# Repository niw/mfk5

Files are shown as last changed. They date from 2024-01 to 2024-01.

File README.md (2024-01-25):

mfk5
====

A prototype keyboard that contains enough features to make a full size
split keyboard. mfk5 is My first keyboard, 5 keys.

This project has concluded and there is a successor, a real full size
split keyboard project, [mfk60](https://github.com/niw/mfk60).

Original Goal
-------------

The goal is testing a design for each component, footprint, and
production process for layered plate design.

- Use [Gateron Low-Profile switches](https://gateron.com/products/gateron-ks-33-low-profile-switch-set?VariantsId=10275)
  on [Hot-Swap socket](https://gateron.com/products/gateron-low-profile-switch-hot-swap-pcb-socket?VariantsId=10234).
- Use [Gateron Low-Profile 2U stabilizer](https://gateron.com/products/gateron-low-profile-plate-mounted-stabilizer?VariantsId=10478),
  which is top plate mount.

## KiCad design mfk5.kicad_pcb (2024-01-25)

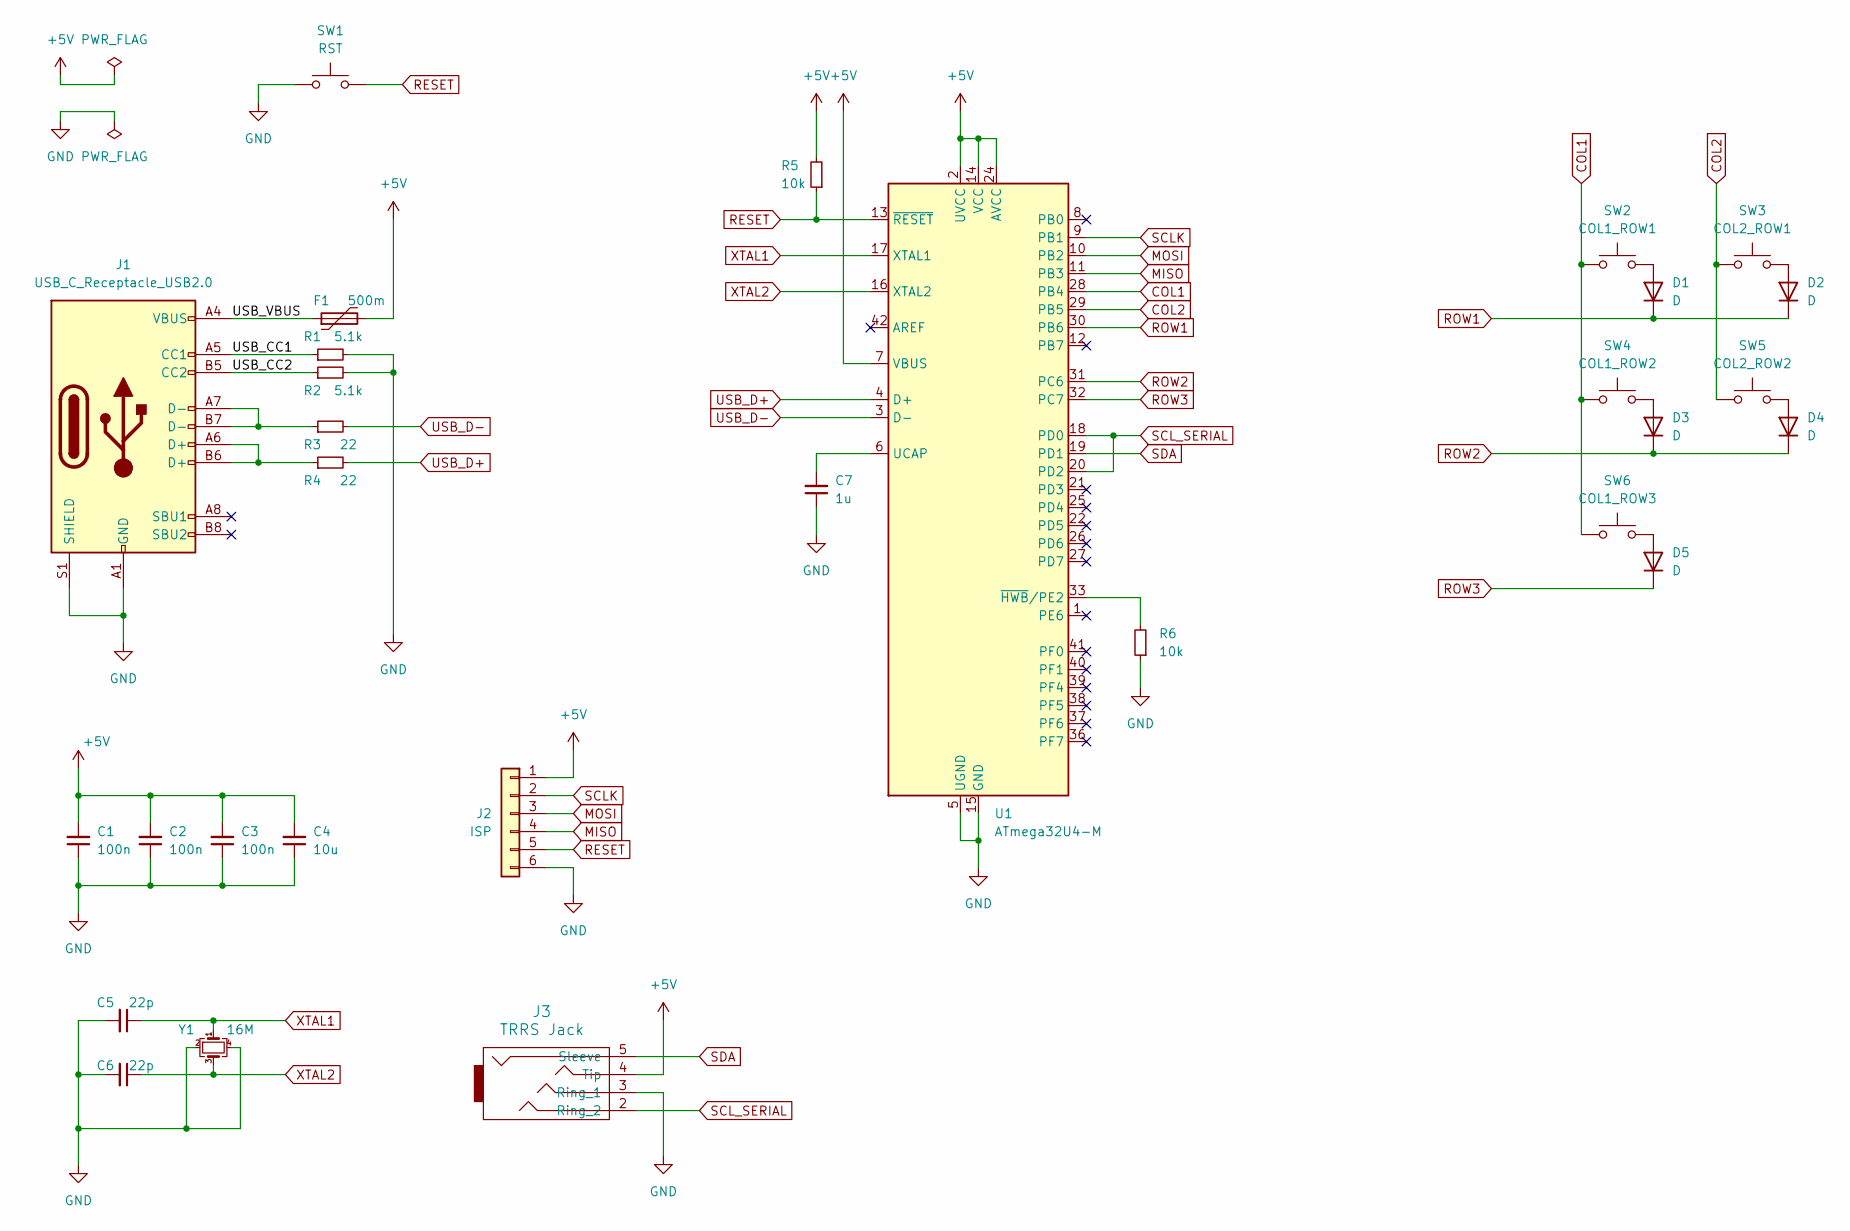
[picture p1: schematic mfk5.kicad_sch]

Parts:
C1, C2, C3: 100n; C_0805_2012Metric_Pad1.18x1.45mm_HandSolder; LCSC C49678
C4: 10u; C_0805_2012Metric_Pad1.18x1.45mm_HandSolder; LCSC C15850
C5, C6: 22p; C_0805_2012Metric_Pad1.18x1.45mm_HandSolder; LCSC C1804
C7: 1u; C_0805_2012Metric_Pad1.18x1.45mm_HandSolder; LCSC C28323
D1, D2, D3, D4, D5: D; D_SOD-123; LCSC C81598
F1: 500m; Fuse_1206_3216Metric_Pad1.42x1.75mm_HandSolder; LCSC C75464
J1: USB_C_Receptacle_USB2.0; USB_C_Receptacle_HRO_TYPE-C-31-M-12; LCSC C2982555
J2: ISP; PinHeader_1x06_P2.54mm_Vertical
J3: TRRS Jack; TRRS_Jack_3.5mm_PJ320A
R1, R2: 5.1k; R_0805_2012Metric_Pad1.20x1.40mm_HandSolder; LCSC C27834
R3, R4: 22; R_0805_2012Metric_Pad1.20x1.40mm_HandSolder; LCSC C17561
R5, R6: 10k; R_0805_2012Metric_Pad1.20x1.40mm_HandSolder; LCSC C17414
SW1: RST; SW_Push_3.5x6mm_THT
SW2: COL1_ROW1; Gateron_Low_Profile_Socket
SW3: COL2_ROW1; Gateron_Low_Profile_Socket
SW4: COL1_ROW2; Gateron_Low_Profile_Socket
SW5: COL2_ROW2; Gateron_Low_Profile_Socket
SW6: COL1_ROW3; Gateron_Low_Profile_Socket_Stabilizer_2U
U1: ATmega32U4-M; QFN-44-1EP_7x7mm_P0.5mm_EP5.2x5.2mm; LCSC C112161
Y1: 16M; Crystal_SMD_3225-4Pin_3.2x2.5mm_HandSoldering; LCSC C255949

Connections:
+5V: C1.2, C2.2, C3.2, C4.2, F1.2, J2.1, J3.4 (Tip), R5.2, U1.2 (UVCC), U1.7 (VBUS), U1.14 (VCC), U1.24 (AVCC), U1.34 (VCC), U1.44 (AVCC)
/USB_CC1: J1.A5 (CC1), R1.1
/USB_CC2: J1.B5 (CC2), R2.1
/USB_VBUS: F1.1, J1.A4 (VBUS), J1.A9 (VBUS), J1.B4 (VBUS), J1.B9 (VBUS)
COL1: SW2.1, SW4.1, SW6.1, U1.28 (PB4)
COL2: SW3.1, SW5.1, U1.29 (PB5)
GND: C1.1, C2.1, C3.1, C4.1, C5.2, C6.2, C7.1, J1.A1 (GND), J1.A12 (GND), J1.B1 (GND), J1.B12 (GND), J1.S1 (SHIELD), J2.6, J3.3 (Ring_1), R1.2, R2.2, R6.1, SW1.2, U1.5 (UGND), U1.15 (GND), U1.23 (GND), U1.35 (GND), U1.43 (GND), U1.45 (GND), Y1.2, Y1.4
MISO: J2.4, U1.11 (PB3)
MOSI: J2.3, U1.10 (PB2)
unnamed: D1.2 (A), SW2.2
unnamed: D2.2 (A), SW3.2
unnamed: D3.2 (A), SW4.2
unnamed: D4.2 (A), SW5.2
unnamed: D5.2 (A), SW6.2
unnamed: J1.A6 (D+), J1.B6 (D+), R4.1
unnamed: J1.A7 (D-), J1.B7 (D-), R3.1
unnamed: C7.2, U1.6 (UCAP)
unnamed: R6.2, U1.33 (~HWB/PE2)
RESET: J2.5, R5.1, SW1.1, U1.13 (~RESET)
ROW1: D1.1 (K), D2.1 (K), U1.30 (PB6)
ROW2: D3.1 (K), D4.1 (K), U1.31 (PC6)
ROW3: D5.1 (K), U1.32 (PC7)
SCLK: J2.2, U1.9 (PB1)
SCL_SERIAL: J3.2 (Ring_2), U1.18 (PD0), U1.20 (PD2)
SDA: J3.5 (Sleeve), U1.19 (PD1)
USB_D+: R4.2, U1.4 (D+)
USB_D-: R3.2, U1.3 (D-)
XTAL1: C5.1, U1.17 (XTAL1), Y1.1
XTAL2: C6.1, U1.16 (XTAL2), Y1.3

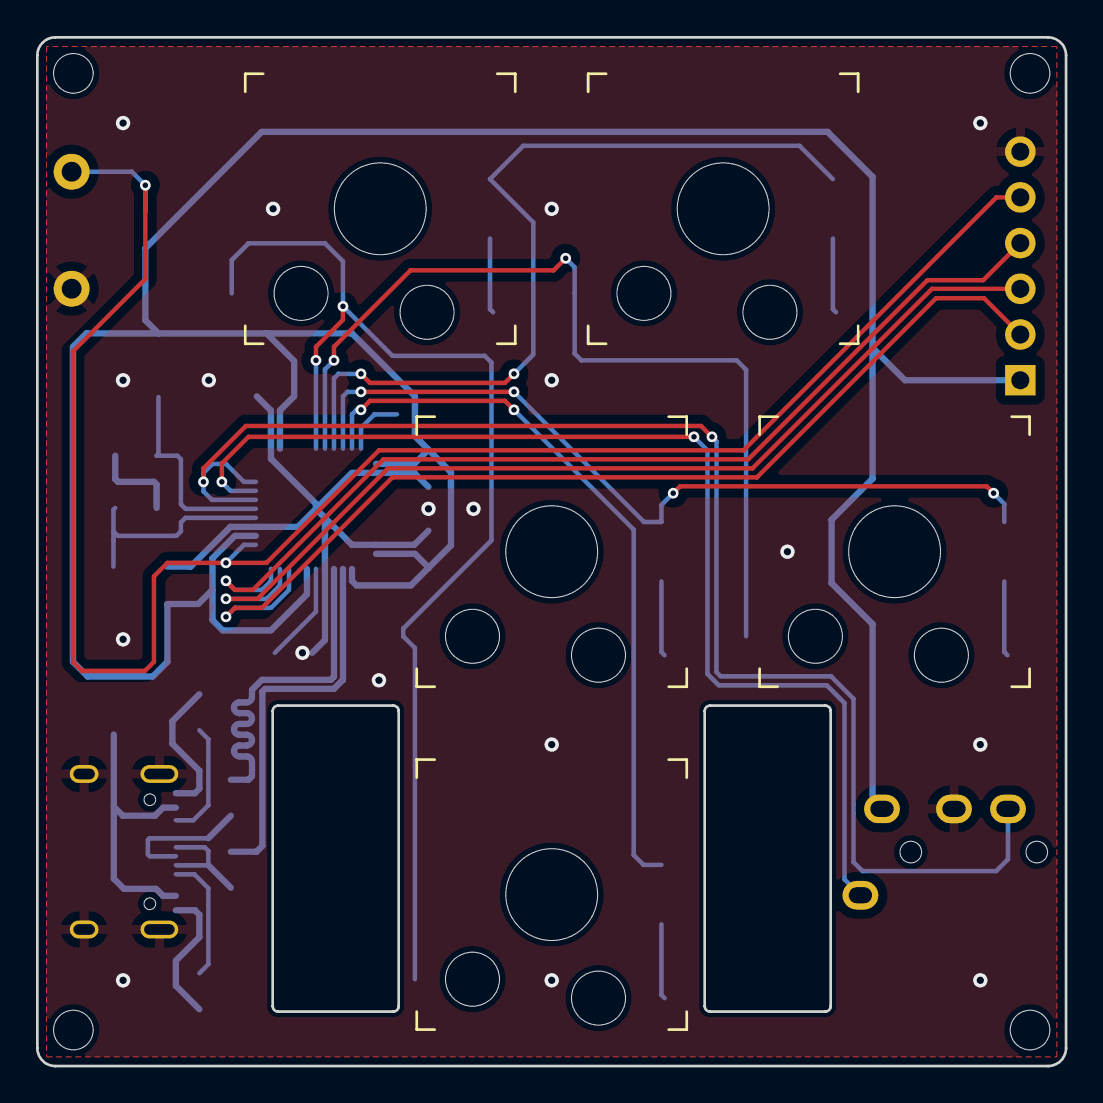
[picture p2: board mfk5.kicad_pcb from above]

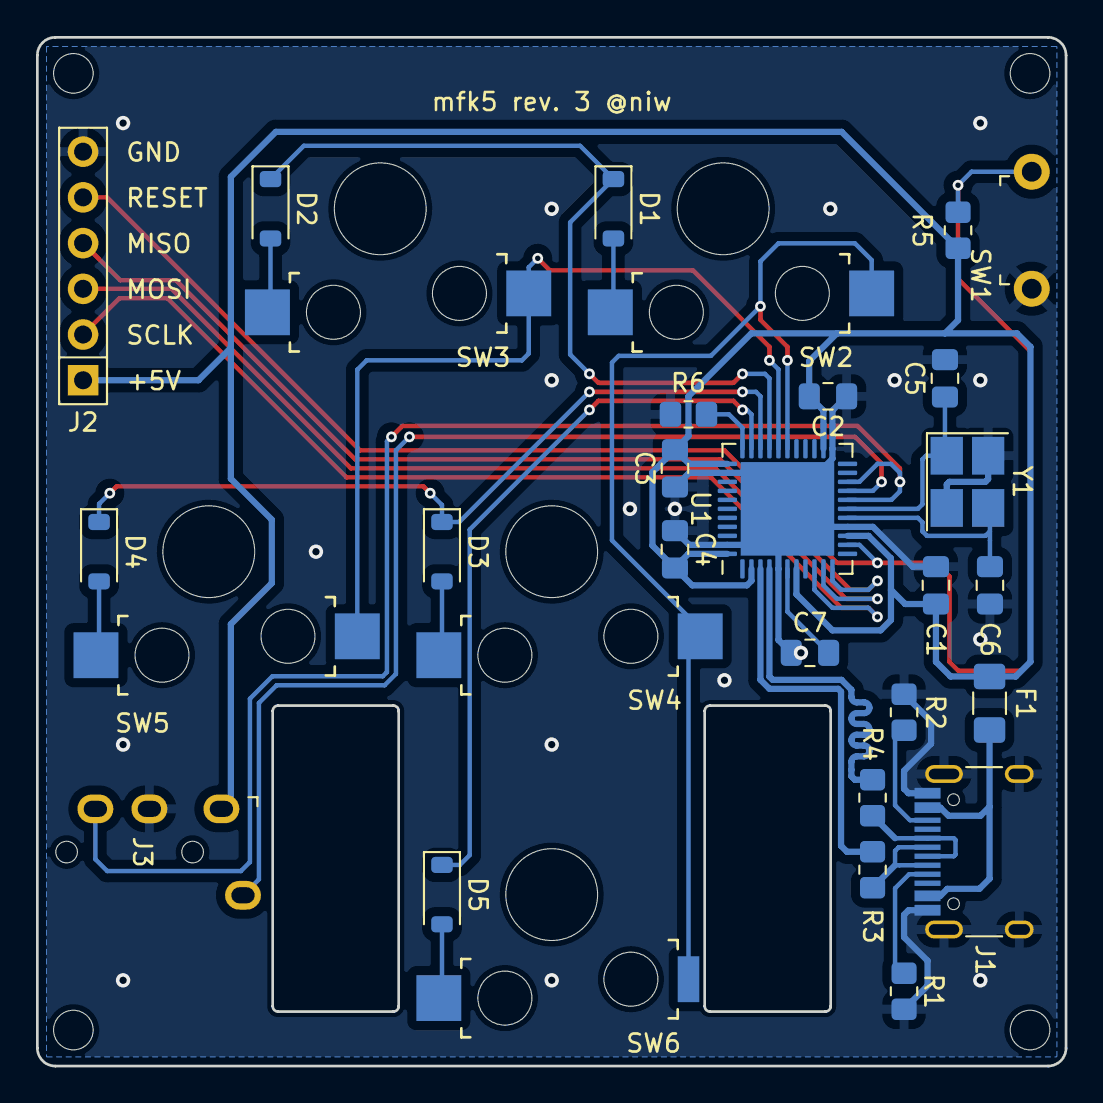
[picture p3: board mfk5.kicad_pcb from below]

Board: 2 copper layers, 57.2 x 57.2 mm, 34 parts (25 on the bottom side), 29 nets.

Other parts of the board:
MH1, MH2, MH3, MH4: MountingHole_2.2mm_M2

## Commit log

2023-06-21 Add mfk5.
    Rev. 1, Initial submit to JLCPCB.
    [mfk5.kicad_pcb, mfk5.kicad_sch, mfk5_top_panel.kicad_pcb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]
2024-01-25 Update mfk5 layout.
    [mfk5.kicad_pcb, mfk5_top_panel.kicad_pcb]
2024-01-25 Add Gateron Low Profile for middle plate.
2024-01-25 Add middle plate.
    [mfk5_middle_plate.kicad_pcb, mfk5_middle_plate.kicad_sch]
2024-01-25 Increment revision.
    - Rev. 2
    - Update title blocks.
    [mfk5.kicad_pcb, mfk5.kicad_sch, mfk5_middle_plate.kicad_pcb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]
2024-01-25 Add ATmega32u4 and related components.
    Stop using Pro Micro, going to use PCBA to SMT components.
    [mfk5.kicad_pcb, mfk5.kicad_sch, mfk5_middle_plate.kicad_pcb]
2024-01-25 Remove unused Pro Micro symbol and footprint.
